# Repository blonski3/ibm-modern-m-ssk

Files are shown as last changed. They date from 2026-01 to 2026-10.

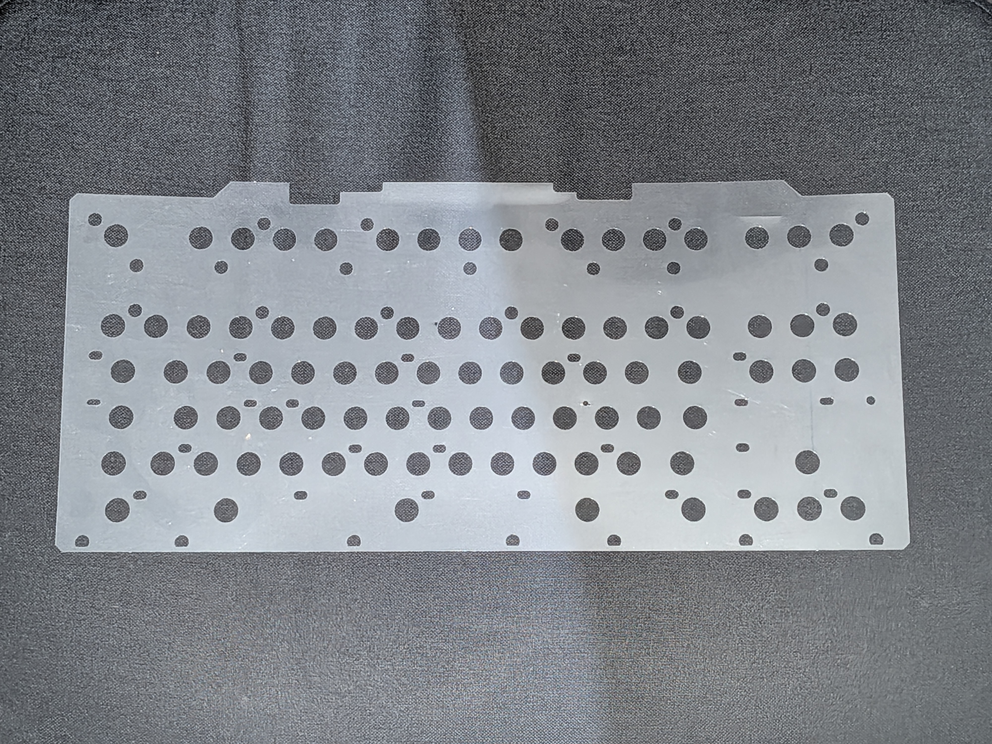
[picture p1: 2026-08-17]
docs/measurements/PXL_20260717_220600276.jpg

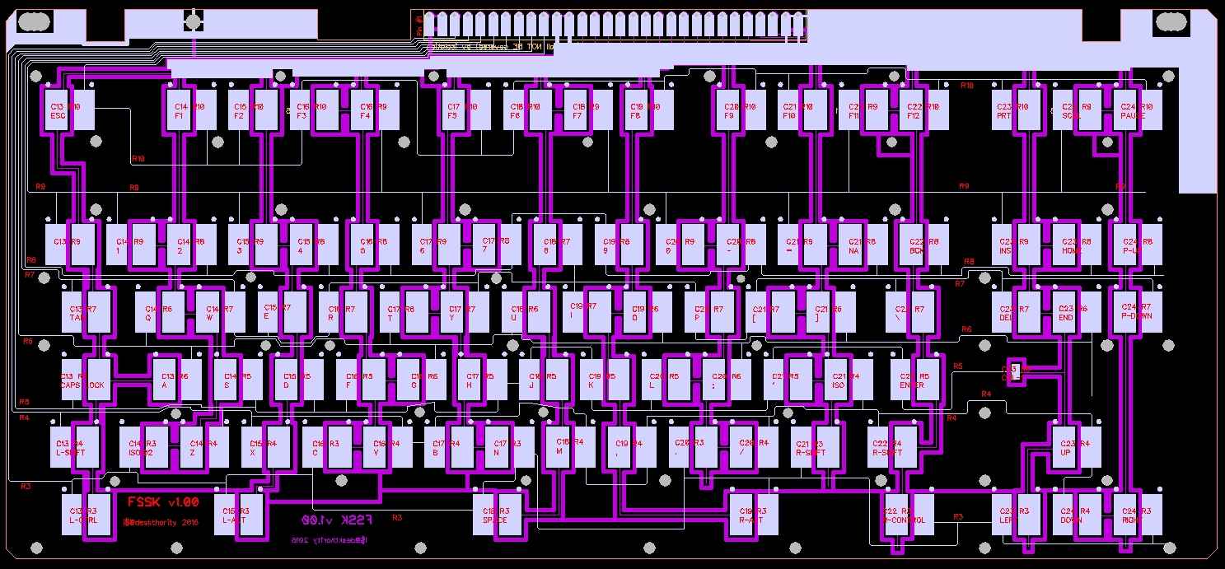
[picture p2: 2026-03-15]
docs/FSSK v1.00/FSSK Diptrace Gerber v1.00/FSSK V1.00 - All layers from Gerber.jpg

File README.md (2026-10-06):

# sources:

[Bolt Mod, A Comprehensive Tutorial: IBM Model M SSK 1991](https://imgur.com/gallery/bolt-mod-comprehensive-tutorial-ibm-model-m-ssk-1991-arUYken)

[FSSK v1.00 - Installation & Users Manual](https://deskthority.net/viewtopic.php?t=13551)

[Request for Permission to Integrate Zephyr PF1550 PMIC Drivers into ZMK #2958](https://github.com/zmkfirmware/zmk/issues/2958)

[nRF52840 Product Specification v1.5](https://docs.nordicsemi.com/viewer/book-attachment/de~7rocmcN70bRHnA4~zJA/H1GC97m6GZQEaMxKCN6OOg-de~7rocmcN70bRHnA4~zJA)

[nPM1300 Product Specification v1.3](https://docs.nordicsemi.com/viewer/book-attachment/ZO1FVHHS04YNNMSlbsZ0Kg/KbFbu1gXgIMOyTgBK7q46A-ZO1FVHHS04YNNMSlbsZ0Kg)

[Keyboard Layout Editor NG - IBM Model M](https://editor.keyboard-tools.xyz/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)

[WR-PHD Pin Header drawing](https://www.we-online.com/components/products/datasheet/61300811021.pdf)

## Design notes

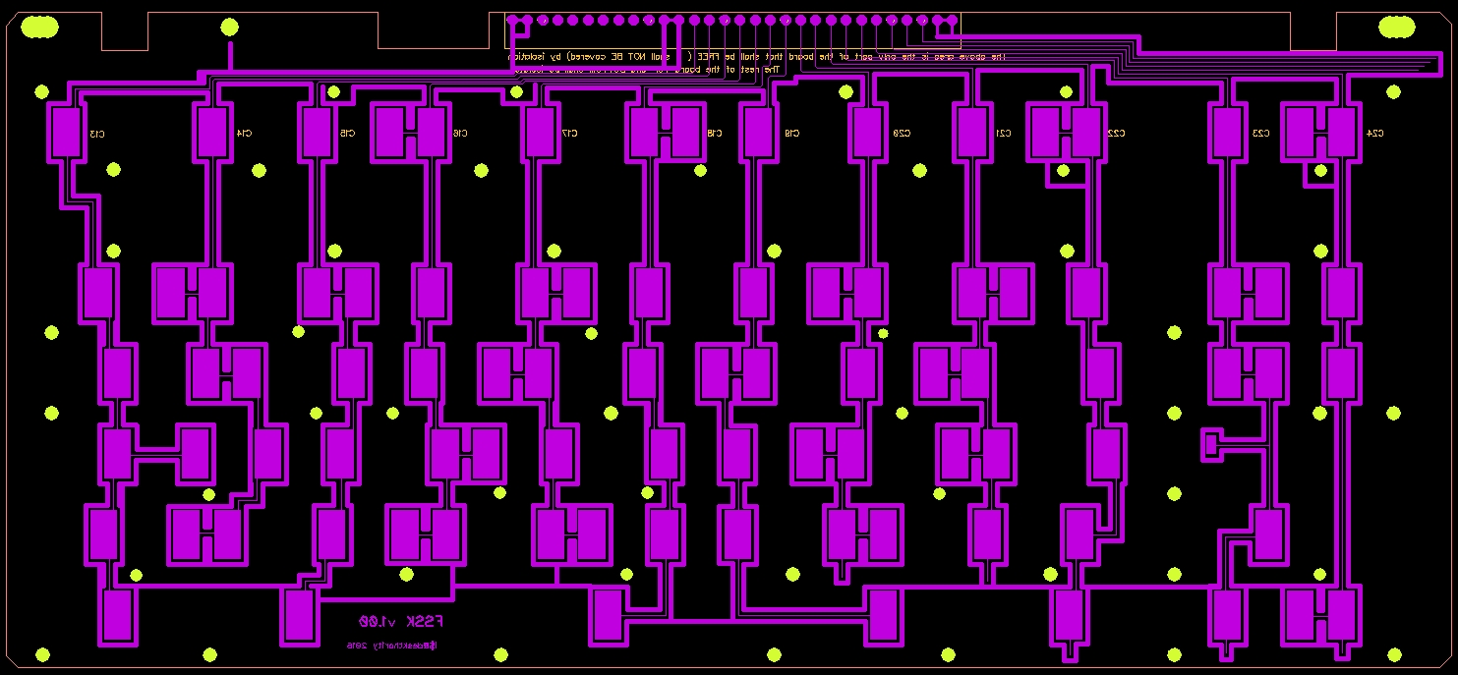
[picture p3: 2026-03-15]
docs/FSSK v1.00/FSSK Diptrace Gerber v1.00/FSSK V1.00 - Bottom layer from Gerber.jpg

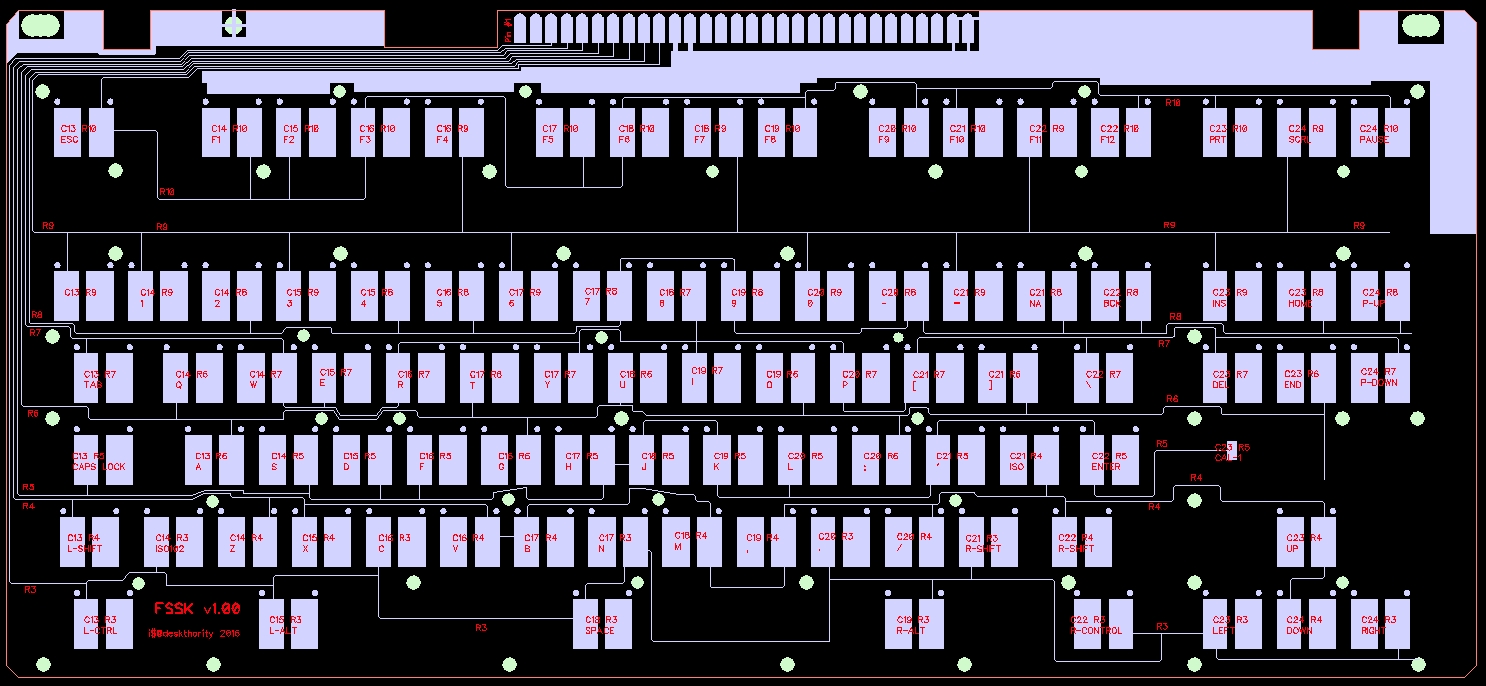
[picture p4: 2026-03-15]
docs/FSSK v1.00/FSSK Diptrace Gerber v1.00/FSSK V1.00 - Top layer from Gerber.jpg

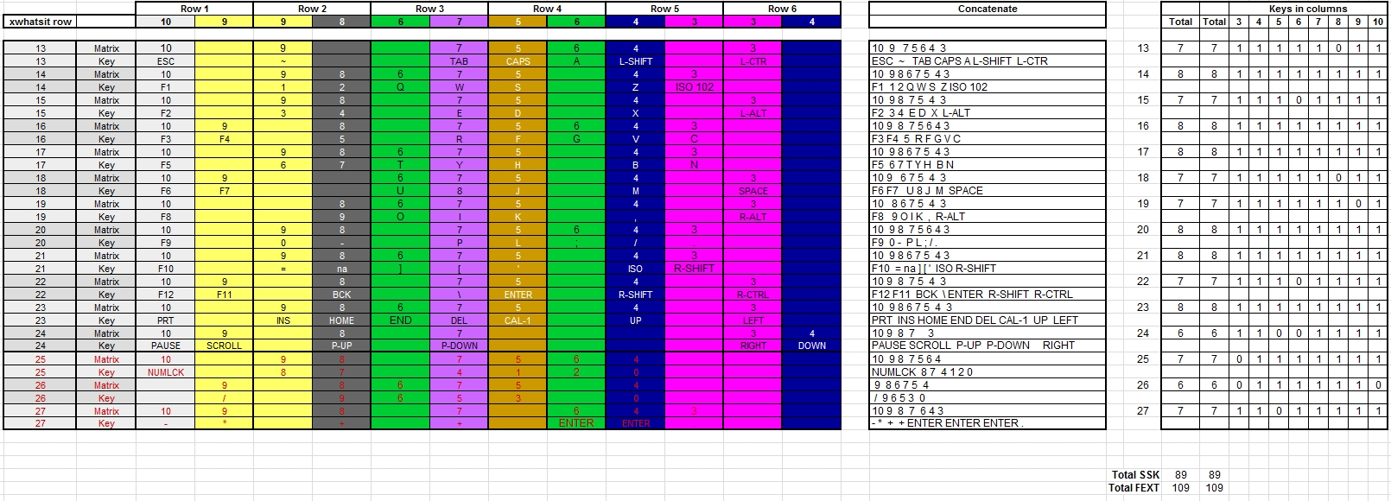
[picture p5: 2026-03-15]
docs/FSSK v1.00/FSSK v1.00 - Matrix table.jpg

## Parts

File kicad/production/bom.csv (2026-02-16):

Designator | Footprint | Quantity | Value | LCSC Part #
C1, C17, C18, C2 | 0402 | 4 | 12p | C526985
C10, C13, C22 | 0402 | 3 | NC | ~
C11 | 0402 | 1 | 100p | C106200
C12, C5, C7, C8 | 0402 | 4 | 100n | C60474
C14, C15, C27, C32, C33 | 0603 | 5 | 1u | C559769
C16 | 0402 | 1 | 47n | C327054
C20, C21, C6 | 0603 | 3 | 4.7u | C277476
C28 | 0603 | 1 | 2.2u | C309478
C29, C30, C31 | 0603 | 3 | 10u | C596327
C3 | 0402 | 1 | 0.8p | C326068
C4 | 0402 | 1 | 0.5p | C327230
C9 | 0402 | 1 | 820p | C726612
D2 | LED-SMD_4P-L1.6-W1.5-TR-1 | 1 | LED_RGB | C3029071
E1 | SON-6_L1.4-W1.0-P0.50-TL_USBULC6-2M6 | 1 | TPD2E001DRYR-TP | C2923399
J1 | FPC-SMD_24P-P0.50_TF38-24S-0.5SV-830 | 1 | TF38-24S-0.5SV(830) | C3020653
J2 | CONN-SMD_2P-P1.00_SM02B-SRSS-TB-LF-SN | 1 | S2B-PH-SM4-TB(LF)(SN) | C160402
J5 | CONN-TH_726386-2 | 1 | 726386-2 | C305817
L1 | 0402 | 1 | 4.7n | C304335
L2 | 0603 | 1 | 10u | C86083
L3 | 0402 | 1 | 15n | C381880
L4 | 1008 | 1 | 2.2u | C5349606
Q1 | SOT-23-3_L2.9-W1.3-P1.90-LS2.4-BR | 1 | DMP2123LQ | C3647032
R1 | 0402 | 1 | 10k | C25744
R10 | 0402 | 1 | 470k | C25792
R8, R9 | 0402 | 2 | 5.1k | C25905
SW90 | SW-SMD_L3.9-W3.0-P4.45 | 1 | SW_Push | C720477
U1 | AQFN50P700X700X85_HS-74N | 1 | NRF52840 | C190794
U2 | Nordic_QFN50P500X500X90-33N | 1 | nPM1300-QEAA | C7466043
USBC1 | USB-C_SMD-TYPE-C-31-M-12_1 | 1 | TYPE-C-31-M-12 | C165948
Y1 | Crystal_SMD_2016-4Pin_2.0x1.6mm | 1 | 32MHz | C255896
Y2 | Crystal_SMD_3215-2Pin_3.2x1.5mm | 1 | 32.768 kHz | C99010

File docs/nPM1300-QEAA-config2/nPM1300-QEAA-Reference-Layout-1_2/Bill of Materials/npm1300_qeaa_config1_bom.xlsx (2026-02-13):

Bill of Materials
Device: | nPM1300-QEAA
Configuration No.: | 1
Reference Layout Title: | Full – both BUCKs and LDOs, VINLDO from external sources
Revision: | 1.2
Creation Date: | 2025-06-05
Designator | Value | Description | Footprint Doc | Manufacturer | Manufacturer Part Number | #Column Name Error:' Fitted | Quantity
C1, C5 | 1.0µF | Capacitor, Ceramic, 1.0µF 10V X5R 0603,±10% | 0603 | N.A. | N.A. |  | 2
C2, C3, C4, C7, C8, C9, C10, C11, C12 | 10µF | Capacitor, X5R, ±20% | 0603 | N.A. | N.A. |  | 9
C6 | 2.2µF | Capacitor, Ceramic, X7R, ±10%, 16V | 0603 | Taiyo Yuden | EMK107BB7225KA-T |  | 1
C13 | 100nF | Capacitor, X5R, ±10%, 100nF, 16V | 0201 | N.A. | N.A. |  | 1
L1, L2 | 2.2µH | Inductor, Irms=2.5A, Isat=2.9A, ±20%, DCR=73mΩ | 0806 | Samsung Electro-Mechanics America | CIGT201610EH2R2MNE |  | 2
R1, R2 | 10k | Resistor, ±1%, 0.05W | 0201 | N.A. | N.A. |  | 2
R3 | 47k | Resistor, ±1%, 0.05W | 0201 | N.A. | N.A. |  | 1
R4 | 150k | Resistor, ±1%, 0.05W | 0201 | N.A. | N.A. |  | 1
U1 | nPM1300-QEAA | Li-Ion/Li-Polymer USB-C battery charger with high efficiency buck regulators, LDOs or load switches, LED drivers, TWI and VBUSOUT | QFN-32 | Nordic Semiconductor | nPM1300-QEAA |  | 1
 |  |  |  |  |  |  | 20

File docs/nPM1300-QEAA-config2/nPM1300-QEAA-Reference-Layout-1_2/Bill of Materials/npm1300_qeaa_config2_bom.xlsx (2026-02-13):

Bill of Materials
Device: | nPM1300-QEAA
Configuration No.: | 2
Reference Layout Title: | Simple – one BUCK, LOADSW and LED
Revision: | 1.2
Creation Date: | 2025-06-05
Designator | Value | Description | Footprint Doc | Manufacturer | Manufacturer Part Number | #Column Name Error:' Fitted | Quantity
C1, C5, C14 | 1.0µF | Capacitor, Ceramic, 1.0µF 10V X5R 0603,±10% | 0603 | N.A. | N.A. |  | 3
C2, C4, C7 | 10µF | Capacitor, Ceramic, X5R, ±20%, 10V | 0603 | N.A. | N.A. |  | 3
C6 | 2.2µF | Capacitor, Ceramic, X5R, ±10%, 25V | 0603 | Murata | GRM188R61E225KA12D |  | 1
C13 | 100nF | Capacitor, Ceramic, X5R, ±10%, 25V | 0201 | Murata | GRM033R61E104KE14J |  | 1
L1 | 2.2µH | Inductor, Irms=2.5A, Isat=2.9A, ±20%, DCR=73mΩ | 0806 | Samsung Electro-Mechanics America | CIGT201610EH2R2MNE |  | 1
R1, R2 | 10k | Resistor, ±1%, 0.05W | 0201 | N.A. | N.A. |  | 2
R3 | 47k | Resistor, ±1%, 0.05W | 0201 | N.A. | N.A. |  | 1
U1 | nPM1300-QEAA | Li-Ion/Li-Polymer USB-C battery charger with high efficiency buck regulators, LDOs or load switches, LED drivers, TWI and VBUSOUT | QFN-32 | Nordic Semiconductor | nPM1300-QEAA |  | 1
 |  |  |  |  |  |  | 13

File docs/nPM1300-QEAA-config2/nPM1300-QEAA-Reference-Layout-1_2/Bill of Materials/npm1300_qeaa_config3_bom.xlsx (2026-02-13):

Bill of Materials
Device: | nPM1300-QEAA
Configuration No.: | 3
Reference Layout Title: | Minimal – only battery charging and VSYS output
Revision: | 1.2
Creation Date: | 2025-06-05
Designator | Value | Description | Footprint Doc | Manufacturer | Manufacturer Part Number | #Column Name Error:' Fitted | Quantity
C1, C5 | 1.0µF | Capacitor, Ceramic, 1.0µF 10V X5R 0603,±10% | 0603 | N.A. | N.A. |  | 2
C4 | 10µF | Capacitor, X5R, ±20% | 0603 | N.A. | N.A. |  | 1
C6 | 2.2µF | Capacitor, Ceramic, X7R, ±10%, 16V | 0603 | Taiyo Yuden | EMK107BB7225KA-T |  | 1
C13 | 100nF | Capacitor, X5R, ±10%, 100nF, 16V | 0201 | N.A. | N.A. |  | 1
R1, R2 | 10k | Resistor, ±1%, 0.05W | 0201 | N.A. | N.A. |  | 2
U1 | nPM1300-QEAA | Li-Ion/Li-Polymer USB-C battery charger with high efficiency buck regulators, LDOs or load switches, LED drivers, TWI and VBUSOUT | QFN-32 | Nordic Semiconductor | nPM1300-QEAA |  | 1
 |  |  |  |  |  |  | 8

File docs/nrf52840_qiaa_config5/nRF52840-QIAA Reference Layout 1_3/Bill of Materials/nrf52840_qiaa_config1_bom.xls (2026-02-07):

Bill of material
Device: | nRF52840-QIAA
Title: | Reference Layout Config. 1: VBUS supply, LDO only, USB
Version: | 1.3
Designator | Value | Description | Assembly | Footprint Doc
C1, C2, C17, C18 | 12pF | Capacitor, NP0, ±2% |  | 0402
C3 | 0.8pF | Capacitor, NP0, ±10% |  | 0402
C4 | 0.5pF | Capacitor, NP0, ±10% |  | 0402
C5, C7, C8, C12 | 100nF | Capacitor, X7R, ±10% |  | 0402
C6, C20 | 4.7µF | Capacitor, X7R, ±10% |  | 0603
C9 | 820pF | Capacitor, NP0, ±5% | Not required for Fxx and later | 0402
C10, C13, C22 | N.C. | Not mounted | Not mounted | 0402
C11 | 100pF | Capacitor, NP0, ±5% |  | 0402
C14, C15 | 1.0µF | Capacitor, X7R, ±10% |  | 0603
C19 | 4.7µF | Capacitor, X7S, ±10% |  | 0603
L1 | 4.7nH | High frequency chip inductor ±5% |  | 0402
R1 | 2R2 | Resistor, ±1%, 0.063W |  | 0402
U1 | nRF52840-QIAA | Multi-protocol Bluetooth Low Energy, IEEE 802.15.4, ANT and 2.4GHz proprietary system-on-chip |  | AQFN-73
X1 | 32MHz | XTAL SMD 2016, 32MHz, Cl=8pF, Total Tol: ±40ppm |  | XTAL_2016
X2 | 32.768kHz | XTAL SMD 3215, 32.768kHz, Cl=9pF, Total Tol: ±50ppm |  | XTAL_3215

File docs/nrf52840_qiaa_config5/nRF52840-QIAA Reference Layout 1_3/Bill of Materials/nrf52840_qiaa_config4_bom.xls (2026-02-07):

Bill of material
Device: | nRF52840-QIAA
Title: | Reference Layout Config. 4: VDDH supply, DCDC, USB
Version: | 1.3
Designator | Value | Description | Assembly | Footprint Doc
C1, C2, C17, C18 | 12pF | Capacitor, NP0, ±2% |  | 0402
C3 | 0.8pF | Capacitor, NP0, ±10% |  | 0402
C4 | 0.5pF | Capacitor, NP0, ±10% |  | 0402
C5, C7, C8, C12 | 100nF | Capacitor, X7R, ±10% |  | 0402
C6, C20 | 4.7µF | Capacitor, X7R, ±10% |  | 0603
C9 | 820pF | Capacitor, NP0, ±5% | Not required for Fxx and later | 0402
C10, C13, C22 | N.C. | Not mounted | Not mounted | 0402
C11 | 100pF | Capacitor, NP0, ±5% |  | 0402
C14, C15 | 1.0µF | Capacitor, X7R, ±10% |  | 0603
C16 | 47nF | Capacitor, X7R, ±10% |  | 0402
C19, C21 | 4.7µF | Capacitor, X7S, ±10% |  | 0603
L1 | 4.7nH | High frequency chip inductor ±5% |  | 0402
L2 | 10µH | Chip inductor, IDC,min = 50 mA, ±20% |  | 0603
L3 | 15nH | High frequency chip inductor ±10% |  | 0402
L4 | 10µH | Chip inductor, IDC,min = 80 mA, ±20% |  | 0603
U1 | nRF52840-QIAA | Multi-protocol Bluetooth Low Energy, IEEE 802.15.4, ANT and 2.4GHz proprietary system-on-chip |  | AQFN-73
X1 | 32MHz | XTAL SMD 2016, 32MHz, Cl=8pF, Total Tol: ±40ppm |  | XTAL_2016
X2 | 32.768kHz | XTAL SMD 3215, 32.768kHz, Cl=9pF, Total Tol: ±50ppm |  | XTAL_3215

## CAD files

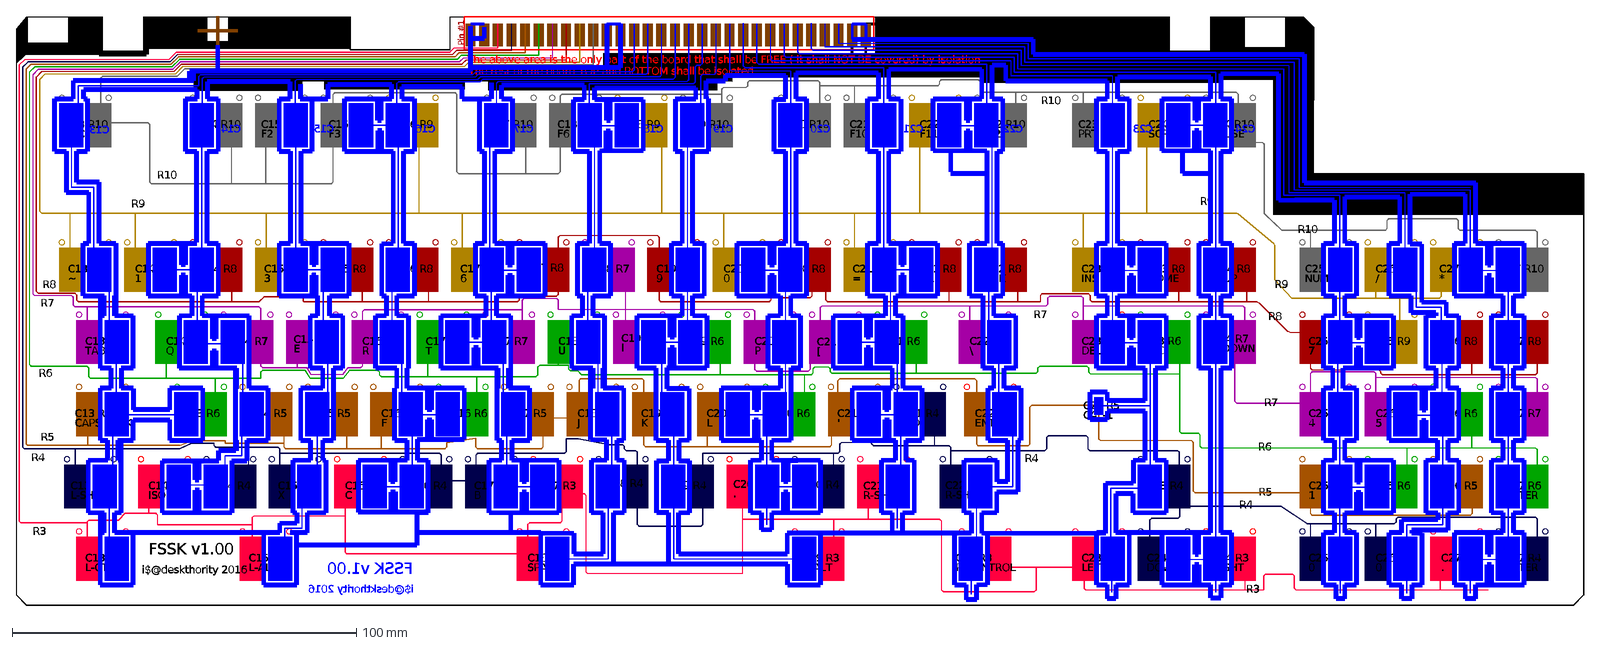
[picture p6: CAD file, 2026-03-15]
docs/FSSK v1.00/FSSK 1.00.dxf
Pin #1
C26 R9
/
C25 R10
NUMLCK
C27 R9
*
C27 R10
-
C25 R8
7
C25 R9
8
C26 R8
9
C27 R8
+
C25 R7
4
C26 R7
5
C26 R6
6
C27 R7
C25 R5
1
C25 R6
2
C26 R5
3
C27 R6
ENTER
C25 R4
0
C26 R4
C27 R3
.
C27 R4
C24 R3
RIGHT
C24 R4
DOWN
C23 R3
LEFT
C23 R4
UP
C23 R7
DEL
C23 R6
END
C24 R7
P-DOWN
C23 R9
INS
C23 R8
HOME
C24 R8
P-UP
C23 R10
PRT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

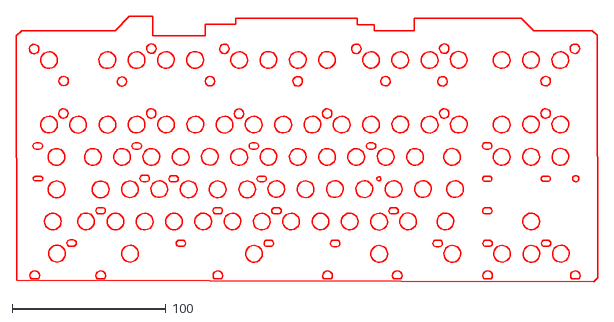
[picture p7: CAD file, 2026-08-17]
docs/measurements/drawing.dxf
377.7 x 172.3

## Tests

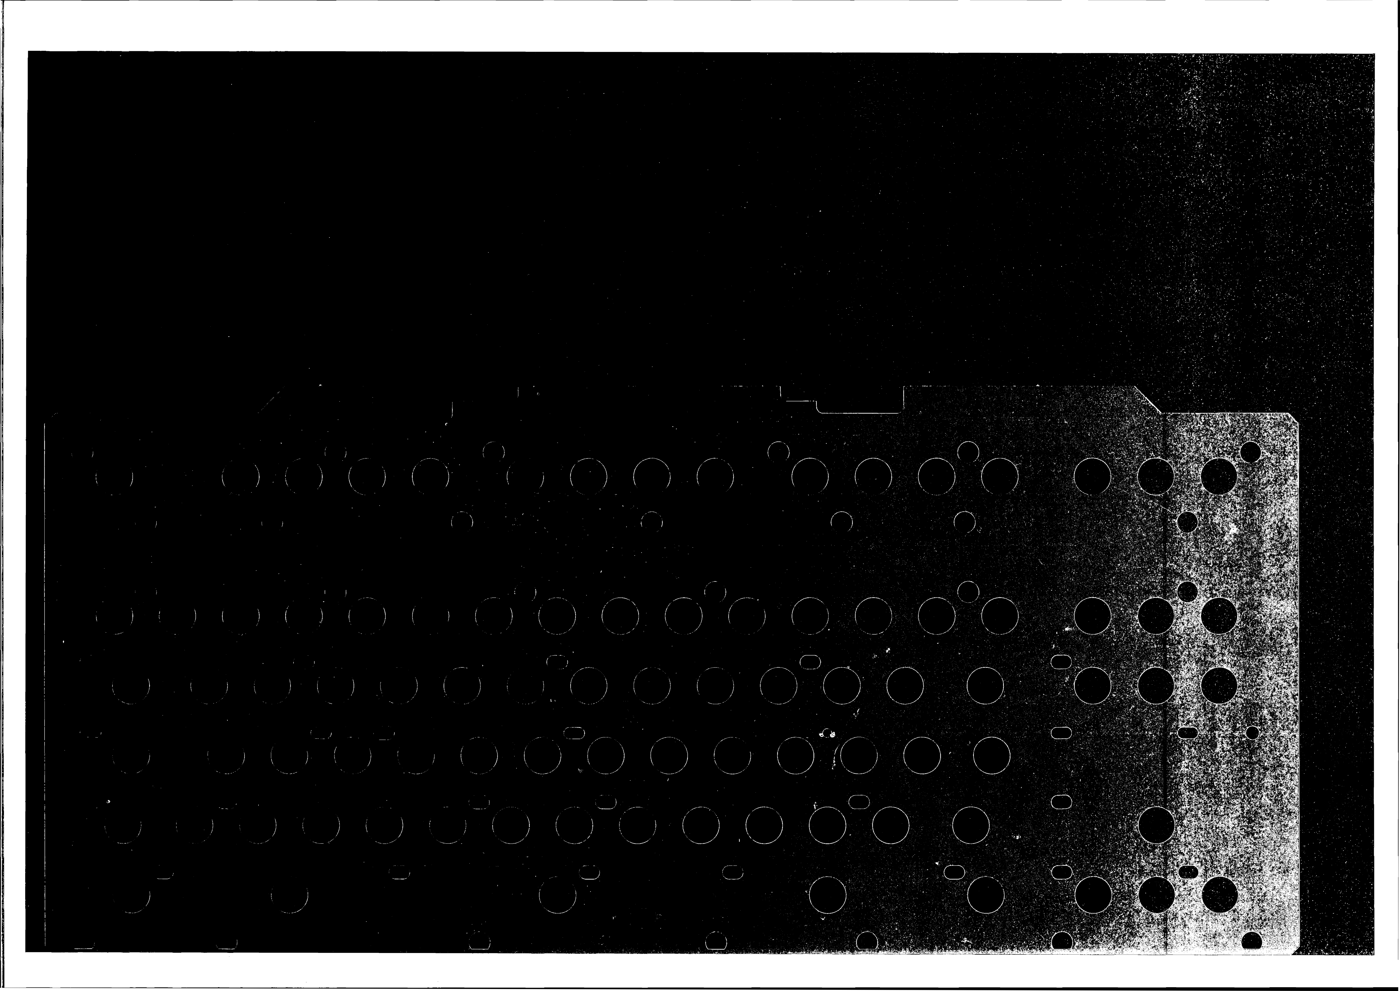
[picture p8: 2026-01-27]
docs/measurements/seperating layer scan.png

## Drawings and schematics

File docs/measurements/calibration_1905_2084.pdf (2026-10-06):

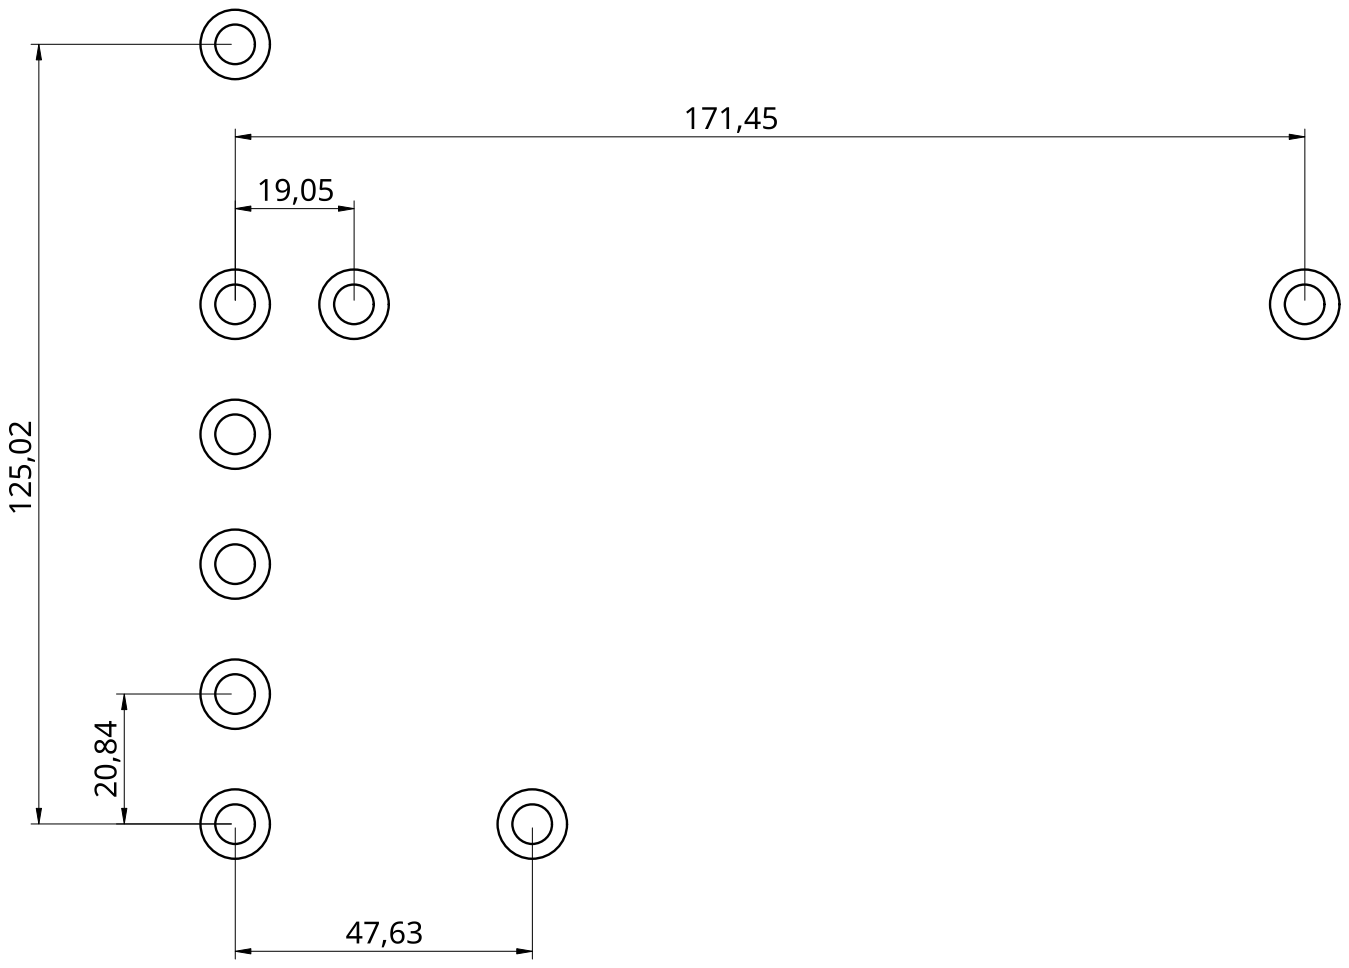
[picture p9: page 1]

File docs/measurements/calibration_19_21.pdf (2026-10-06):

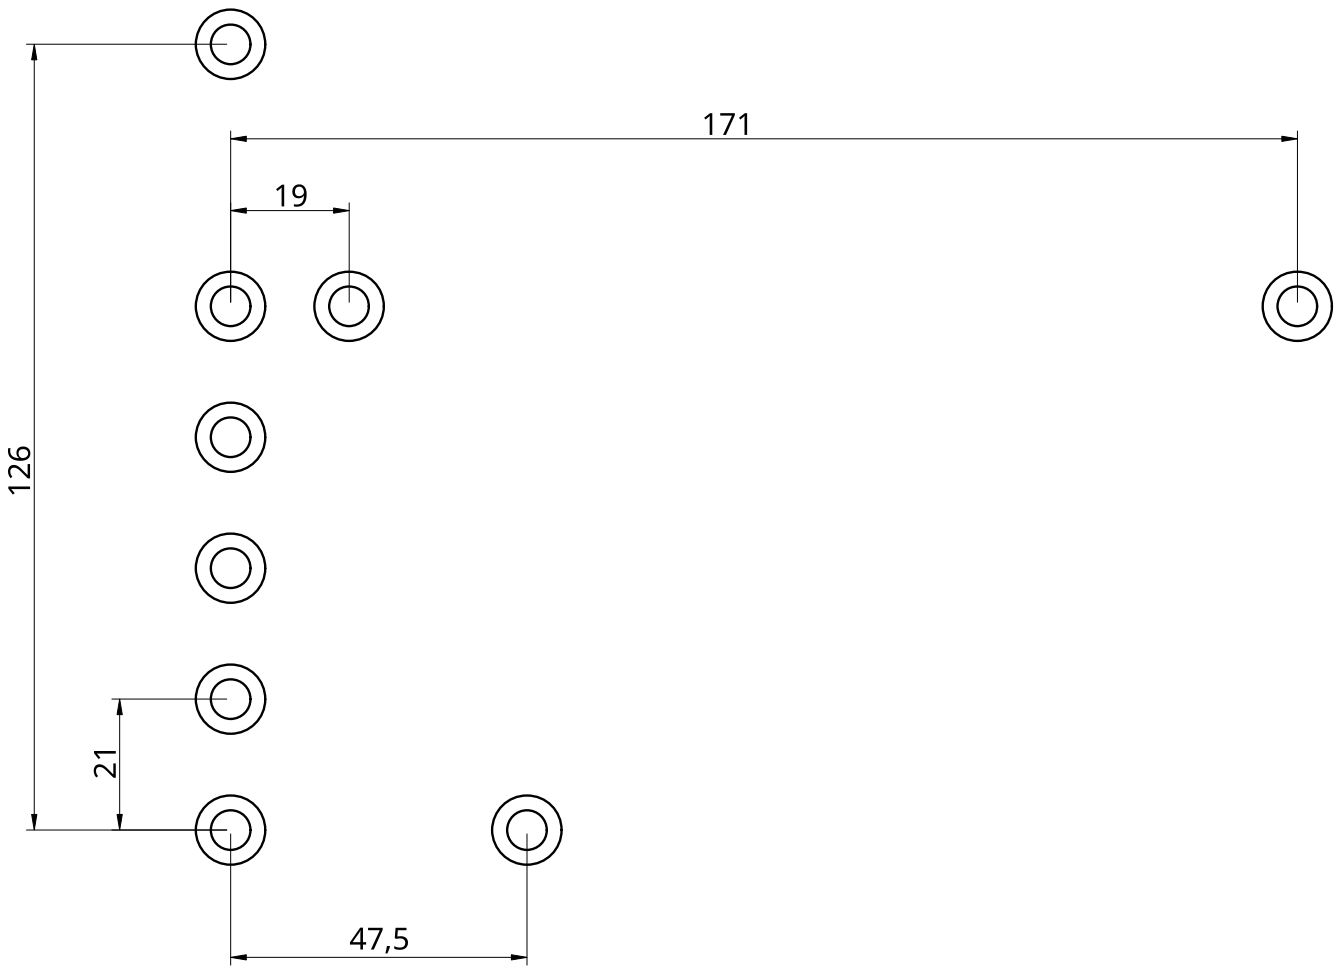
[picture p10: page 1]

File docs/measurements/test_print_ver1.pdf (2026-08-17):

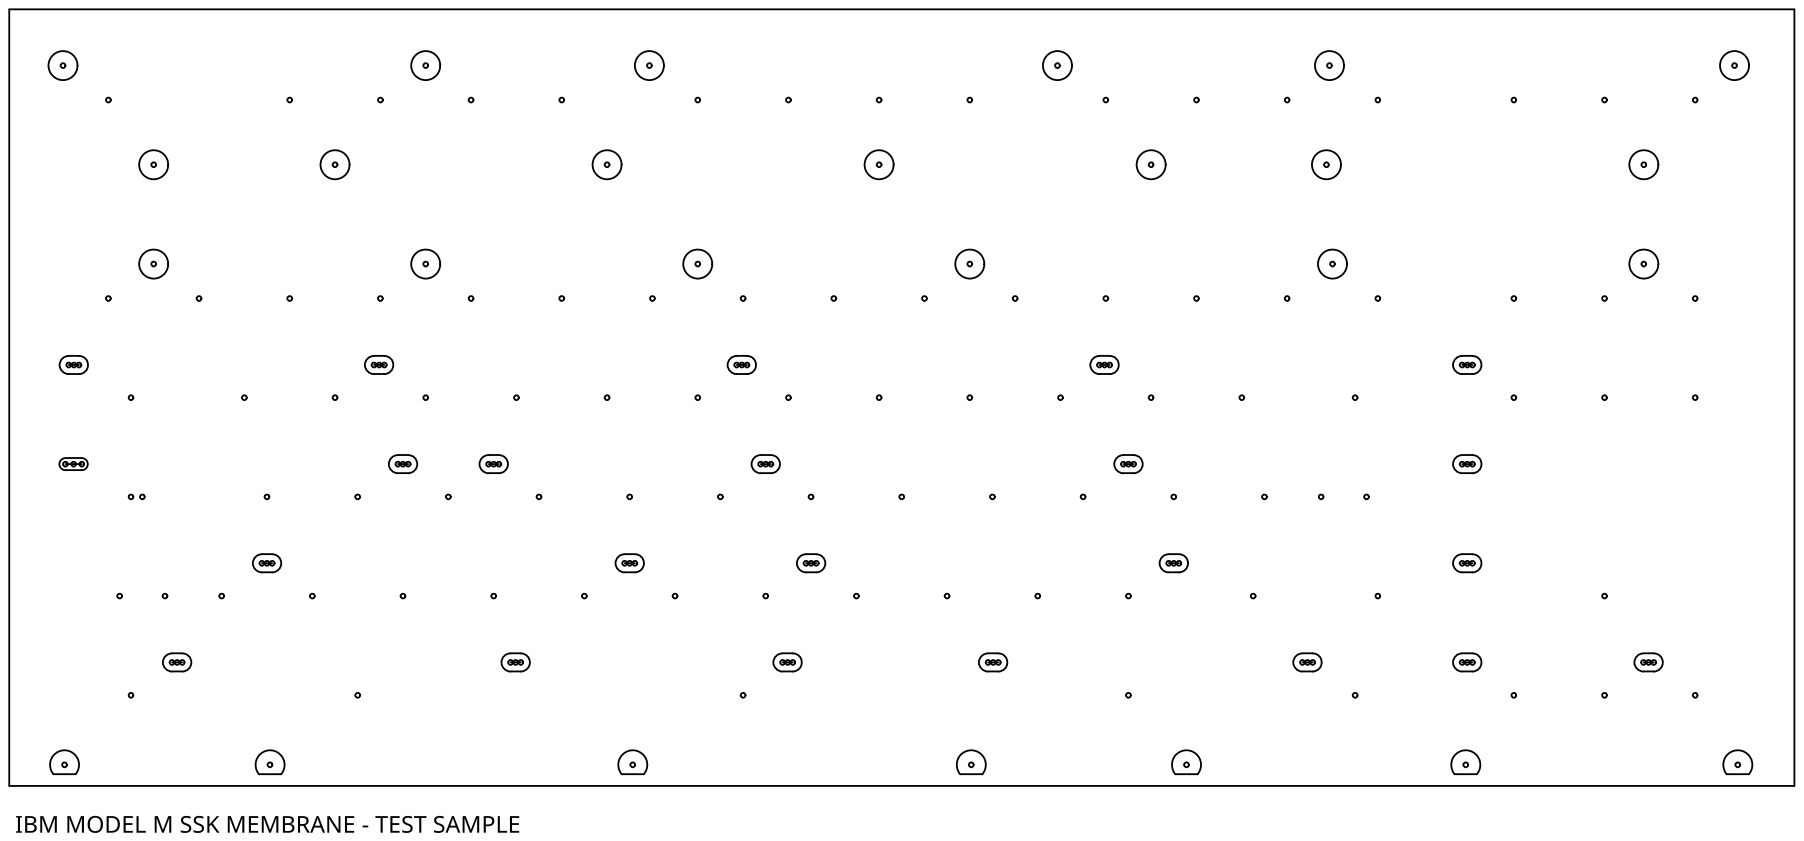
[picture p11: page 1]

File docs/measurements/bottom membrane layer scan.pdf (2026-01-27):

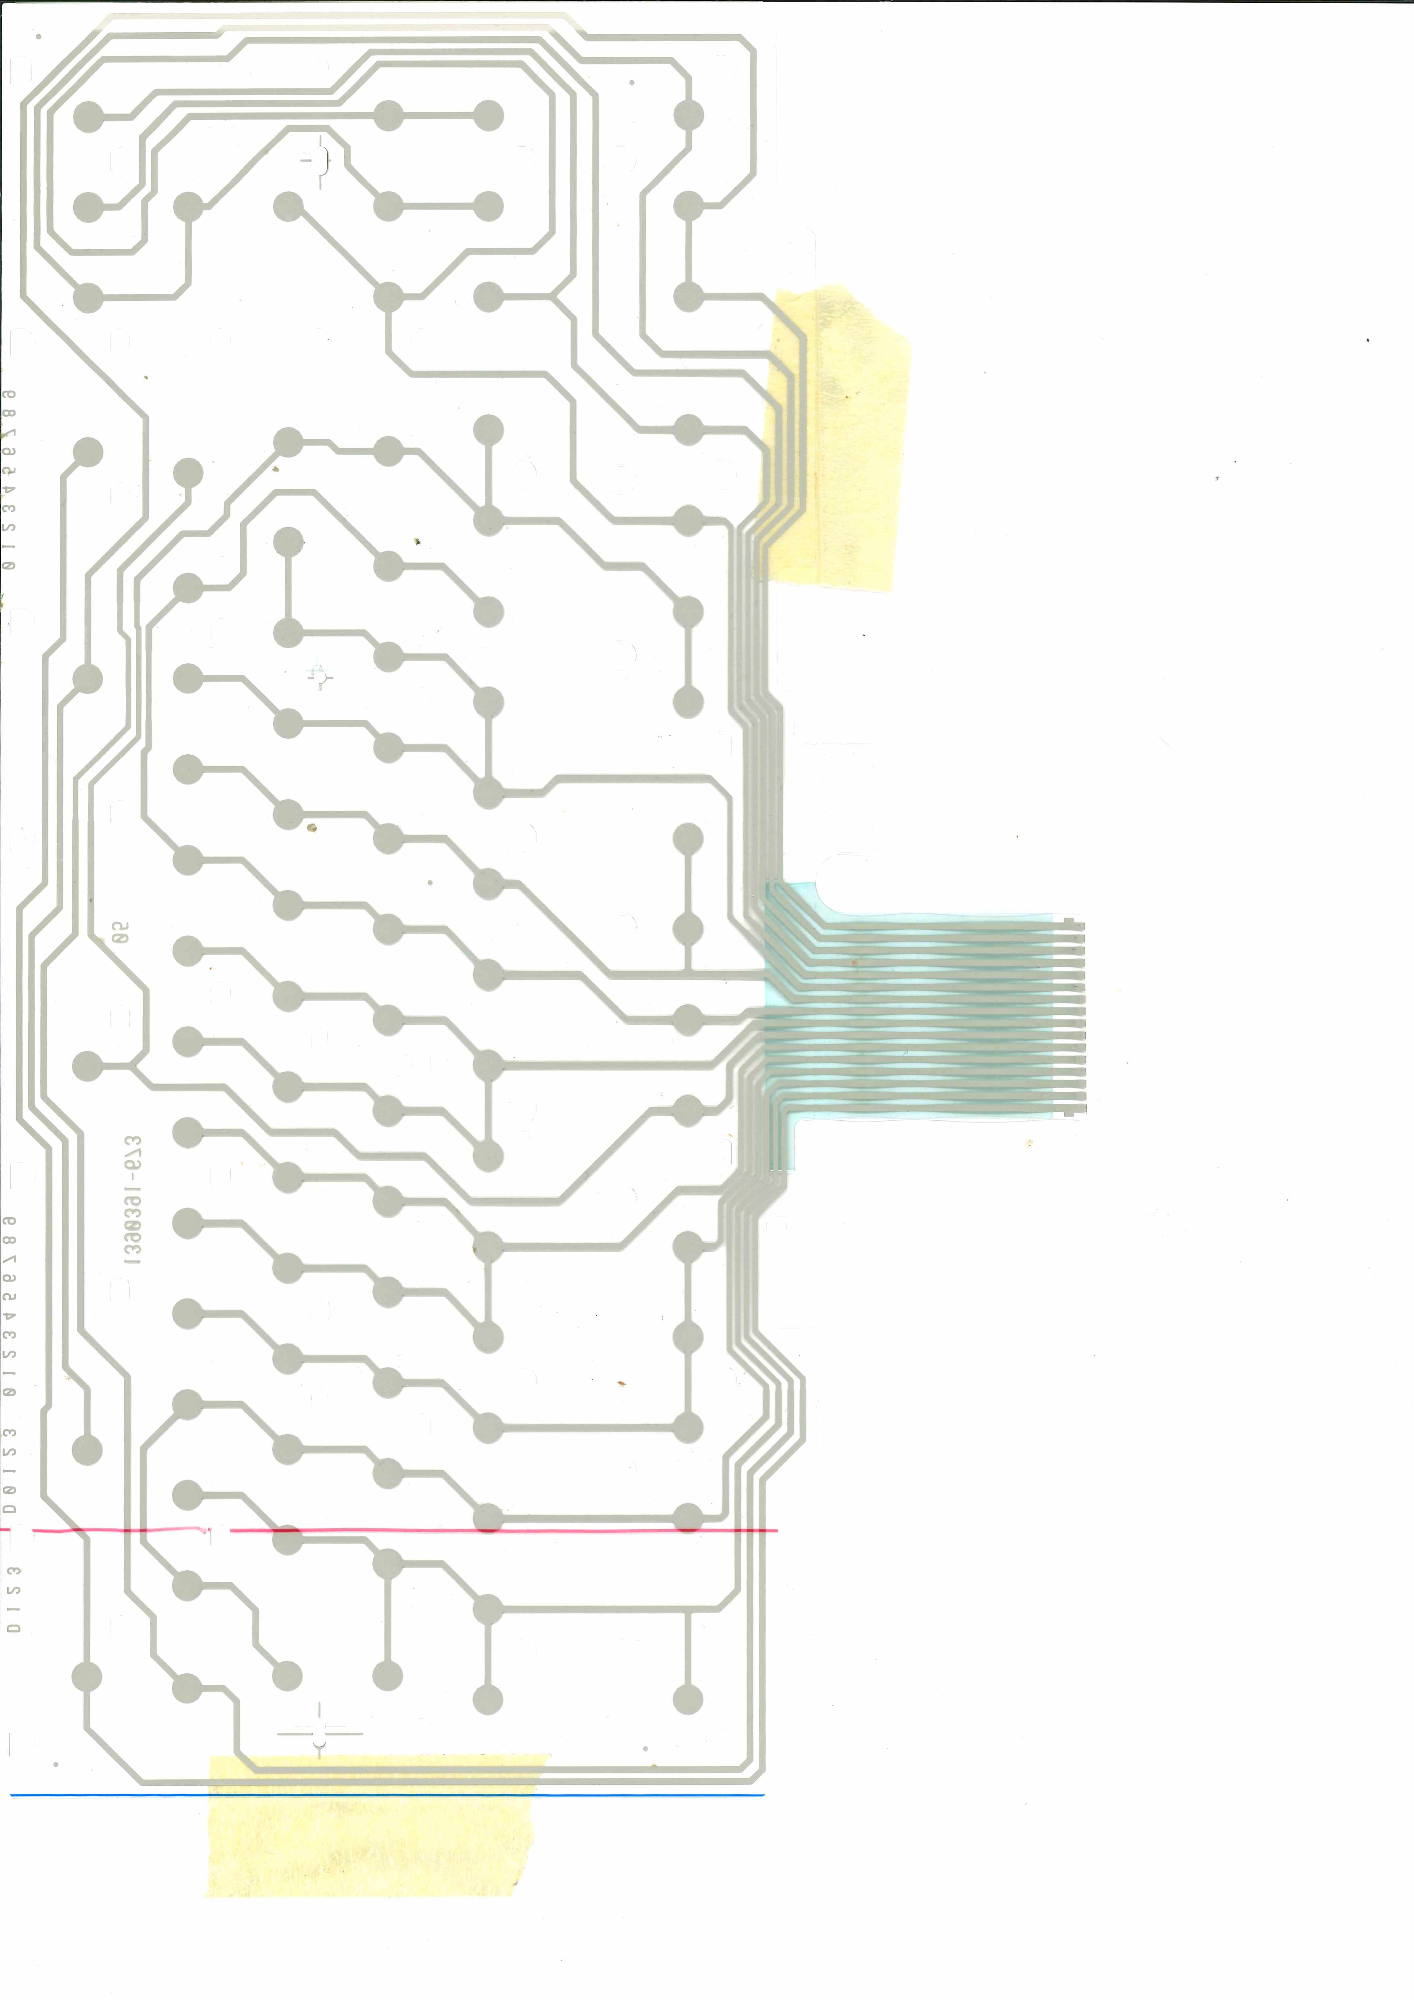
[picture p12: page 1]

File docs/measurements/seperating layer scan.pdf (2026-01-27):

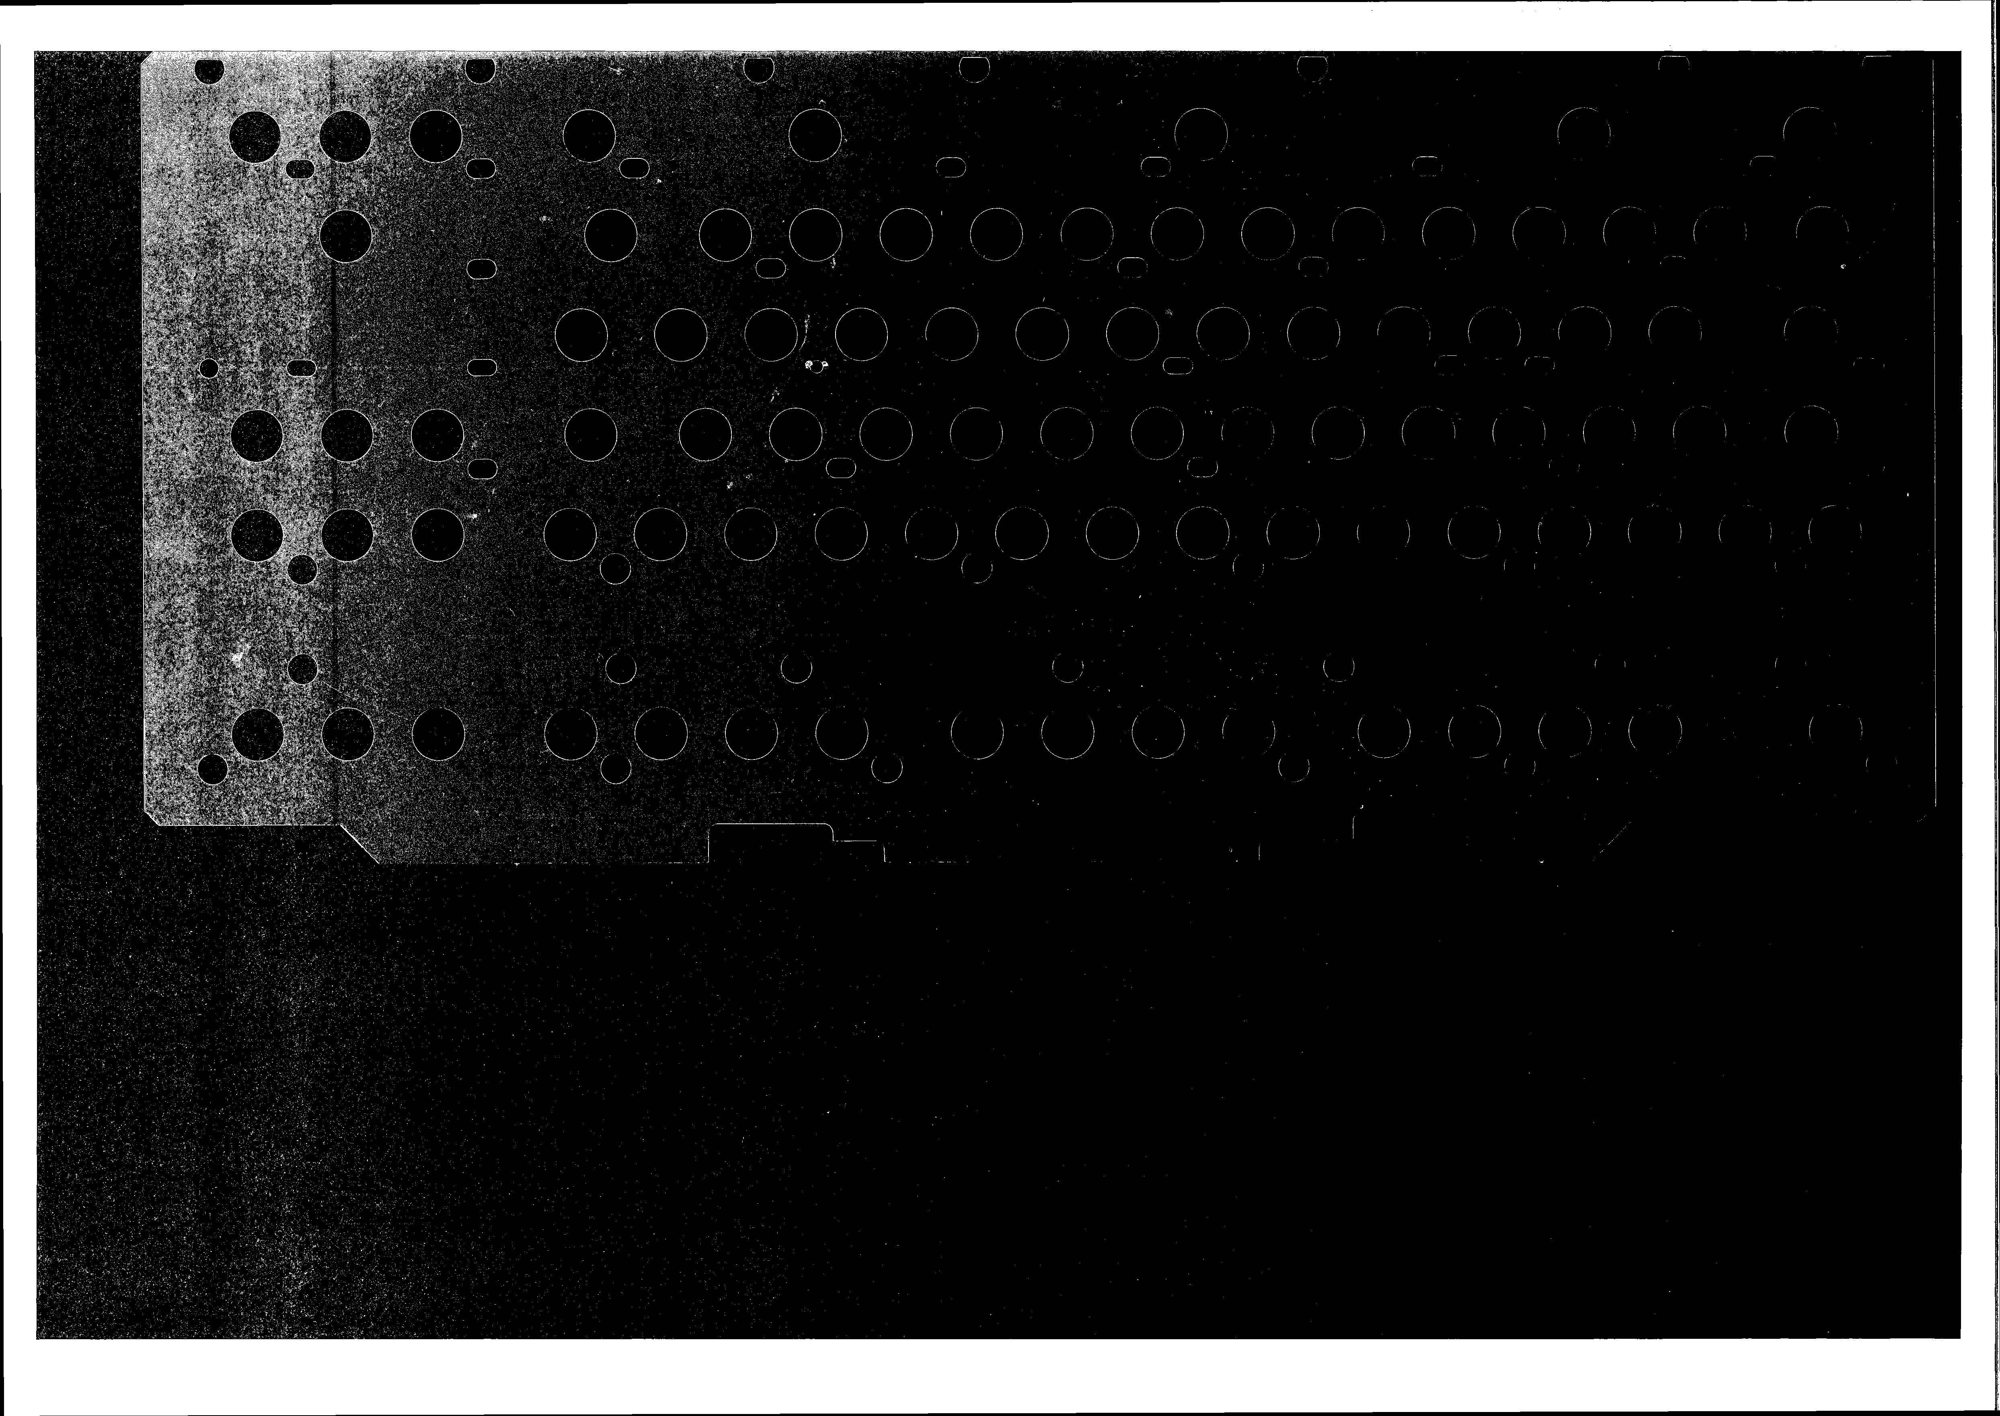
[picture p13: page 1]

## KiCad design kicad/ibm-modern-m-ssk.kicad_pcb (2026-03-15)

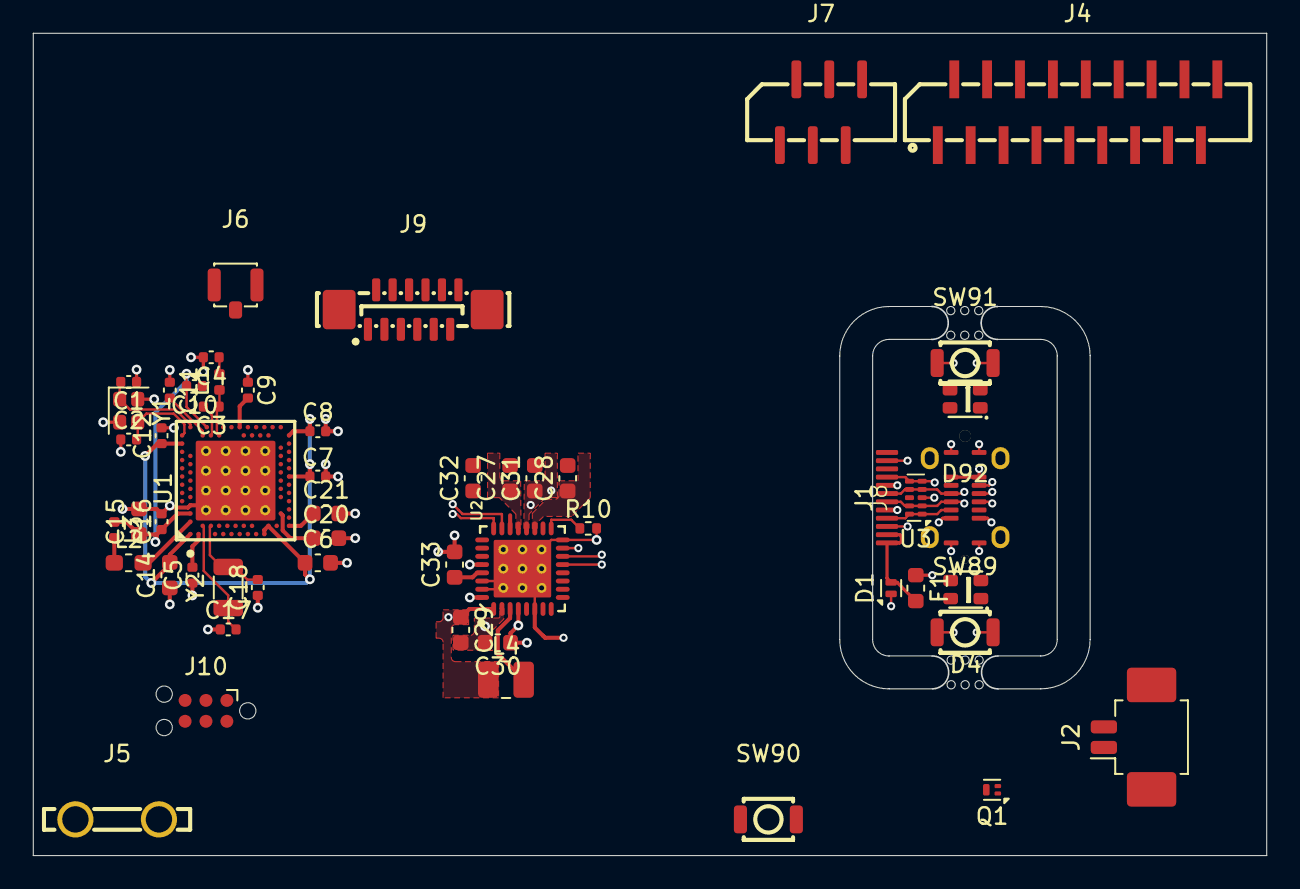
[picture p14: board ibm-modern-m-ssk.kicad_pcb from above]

Board: 4 copper layers, 75.0 x 50.0 mm, 53 parts (0 on the bottom side), 35 nets.

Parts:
C1, C2, C17, C18: 12p; C_0402_1005Metric
C3: 0.8p; C_0402_1005Metric
C4: 0.5p; C_0402_1005Metric
C5, C7, C8, C12: 100n; C_0402_1005Metric
C6, C20, C21: 4.7u; C_0603_1608Metric
C9: 820p; C_0402_1005Metric
C10: NC; C_0402_1005Metric
C11: 100p; C_0402_1005Metric
C14, C15, C27, C32, C33: 1u; C_0603_1608Metric
C16: 47n; C_0402_1005Metric
C28: 2.2u; C_0603_1608Metric
C29, C30, C31: 10u; C_0603_1608Metric
D1: PESDNC2FD5VB; Diodes_DFN1006-2
D4, D92: rgb; WS2812C-2020-V1
F1: BSMD0603L-150; Fuse_0603_1608Metric
J1: TYPE-C-31-D-06; USB-C-SMD_TYPE-C-31-D-06
J2: Molex PicoBlade; Molex_PicoBlade_53261-0271_1x02-1MP_P1.25mm_Horizontal
J4: AFB10-S18LCA-00; FPC-SMD_18P-P1.00_AFB10-S18LCA-00
J5: 726386-2; CONN-TH_726386-2
J6: Conn_Coaxial_Small; IPEX-SMD_3P-L2.6-W2.6-LS3.0_ZCF-CF0001-0002IPEX
J7: AFB10-S06LCA-00; FPC-SMD_6P-P1.00_AFB10-S6LCA-00
J8: FPC_12P_0.5mm
J9: AFC11-S12ICA-00; CONN-SMD-12P_AFC11-S12ICA-00
J10: TC2030; Tag-Connect_TC2030-IDC-NL_2x03_P1.27mm_Vertical
L1: 4.7n; L_0402_1005Metric
L2: 10u; L_0603_1608Metric_Pad1.05x0.95mm_HandSolder
L3: 15n; L_0402_1005Metric
L4: 2.2u; L_1008_2520Metric
Q1: PMZB350UPE,315; DFN1006-3
R10: 470k; R_0402_1005Metric
SW89, SW90, SW91: SW_Push; KEY-SMD_B3U-1000PM
U1: NRF52840; AQFN50P700X700X85_HS-74N
U2: nPM1300-QEAA; Nordic_QFN50P500X500X90-33N
U3: TPD4E05U06DQAR; USON-10_2.5x1.0mm_P0.5mm
Y1: 32MHz; Crystal_SMD_2016-4Pin_2.0x1.6mm
Y2: 32.768 kHz; Crystal_SMD_3215-2Pin

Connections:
/daughterboard/BT_PAIR: J8.3, J9.3, SW89.1
/daughterboard/CC1: J1.A5 (CC1), J8.4, J9.4, U2.23 (CC1), U3.1 (D1+), U3.10 (NC)
/daughterboard/CC2: J1.B5 (CC2), J8.9, J9.9, U2.24 (CC2), U3.5 (D2-), U3.6 (NC)
/daughterboard/LED_DATA: D4.3 (DIN), J8.10, J9.10
/daughterboard/SHPHLD: J8.11, J9.11, SW91.1, U2.15 (SHPHLD)
/motherboard/ANTENNA: C4.1, J6.1 (In), L1.2
/motherboard/DEC4: C10.2, C15.1, C16.1, L3.1, U1.B5 (DEC4), U1.E24 (DEC6)
/motherboard/SWCLK: J10.4, U1.AA24 (SWDCLK)
/motherboard/SWDIO: J10.2, U1.AC24 (SWDIO)
D+: J1.A6 (D+), J1.B6 (D+), J8.6, J9.6, U1.AD6 (D+), U3.2 (D1-), U3.9 (NC)
D-: J1.A7 (D-), J1.B7 (D-), J8.7, J9.7, U1.AD4 (D-), U3.4 (D2+), U3.7 (NC)
GND: C1.1, C2.1, C3.2, C4.2, C5.1, C6.2, C7.2, C8.2, C9.2, C10.1, C11.1, C12.2, C14.1, C15.2, C16.2, C17.1, C18.1, C20.2, C21.2, C27.2, C28.2, C31.2, C32.2, C33.2, D1.1 (A1), D4.2 (VSS), D92.2 (VSS), J1.A1 (GND), J1.A12 (GND), J1.B1 (GND), J1.B12 (GND), J2.2, J5.1, J6.2 (Ext), J8.5, J8.8, J9.5, J9.8, J10.3, J10.5, Q1.1 (G), R10.2, SW89.2, SW90.2, SW91.2, U1.74 (GND), U1.B7 (VSS), U1.F23 (VSS_PA), U2.6 (PVSS2), U2.16 (VSET2), U2.30 (LSIN2/VINLDO2), U2.31 (LSOUT2/VOUTLDO2), U2.33 (AVSS), U3.3 (GND), U3.8 (GND), Y1.2, Y1.4
unnamed: D4.1 (DOUT), D92.3 (DIN)
unnamed: F1.1, J1.A4 (VBUS), J1.A9 (VBUS), J1.B4 (VBUS), J1.B9 (VBUS)
unnamed: L2.1, L3.2
unnamed: J2.1, Q1.2 (S)
unnamed: C3.1, L1.1, U1.H23 (ANT)
unnamed: L2.2, U1.B3 (DCC)
unnamed: C5.2, U1.C1 (DEC1)
unnamed: C11.2, U1.D23 (DEC3)
unnamed: C9.1, U1.N24 (DEC5)
unnamed: C20.1, U1.AC5 (DECUSB)
unnamed: C17.2, U1.D2 (P0.00/XL1), Y2.2
unnamed: C18.2, U1.F2 (P0.01/XL2), Y2.1
unnamed: C1.2, U1.B24 (XC1), Y1.3
unnamed: C2.2, U1.A23 (XC2), Y1.1
unnamed: C33.1, U2.29 (LSOUT1/VOUTLDO1)
unnamed: L4.2, U2.3 (SW1)
unnamed: R10.1, U2.17 (VSET1)
PVSS1: C29.2, C30.2, U2.2 (PVSS1)
VBAT: C28.1, Q1.3 (D), U2.19 (VBAT)
VBUS: C27.1, D1.2 (A2), F1.2, J8.1, J8.2, J9.1, J9.2, U2.21 (VBUS)
VBUSOUT: C21.1, C32.1, U1.AD2 (VBUS), U2.22 (VBUSOUT)
VDD_NRF: C6.1, C7.1, C8.1, C12.1, C14.2, C29.1, J10.1, L4.1, U1.A22 (VDD), U1.AD14 (VDD), U1.AD23 (VDD), U1.B1 (VDD), U1.W1 (VDD), U1.Y2 (VDDH), U2.1 (VOUT1), U2.28 (LSIN1/VINLDO1)
VSYS: C30.1, C31.1, D4.4 (VDD), D92.4 (VDD), J8.12, J9.12, U2.4 (PVDD), U2.20 (VSYS), U2.32 (VOUT2)

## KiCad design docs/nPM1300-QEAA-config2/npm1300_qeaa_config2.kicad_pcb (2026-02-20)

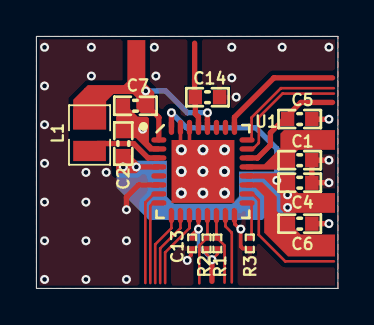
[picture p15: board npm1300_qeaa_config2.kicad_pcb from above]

Board: 4 copper layers, 16.8 x 14.0 mm, 14 parts (0 on the bottom side), 13 nets.

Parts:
C1, C5, C14: 1.0µF; CAPC1608X06L
C2, C4, C7: 10µF; CAPC1608X06L
C6: 2.2µF; CAPC1608X06L
C13: 100nF; CAPC0603X03L_C
L1: 2.2µH; INDC2016X10N
NT1: Net tie; 2 PIN STARPOINT
R1, R2: 10k; RESC0603X03L_C
R3: 47k; RESC0603X03L_C
U1: nPM1300-QEAA; Nordic_QFN50P500X500X90-33N

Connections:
GND: C1.1, C4.1, C5.1, C6.1, C13.2, C14.1, NT1.1, R3.2, U1.6, U1.16, U1.30, U1.31, U1.33
LSOUT1: C14.2, U1.29
PVSS1: C2.1, C7.1, NT1.2, U1.2
SCL: R1.1, U1.14
SDA: R2.1, U1.13
SW1: L1.2, U1.3
VBAT: C6.2, U1.19
VBUSIN: C1.2, U1.21
VBUSOUT: C5.2, U1.22
VDDIO: C13.1, R1.2, R2.2, U1.12
VOUT1: C7.2, L1.1, U1.1, U1.28
VSET1: R3.1, U1.17
VSYS: C2.2, C4.2, U1.4, U1.20, U1.32

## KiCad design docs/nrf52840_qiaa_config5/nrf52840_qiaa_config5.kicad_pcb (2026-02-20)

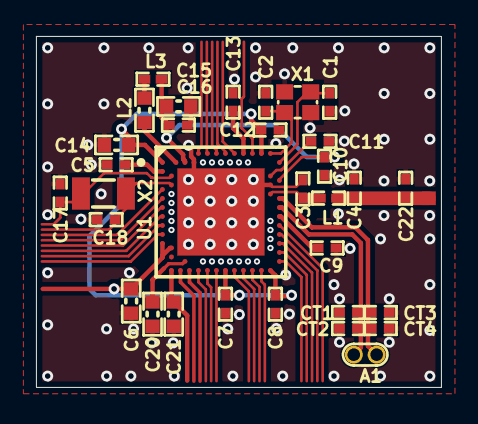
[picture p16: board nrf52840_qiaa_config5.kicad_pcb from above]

Board: 4 copper layers, 22.5 x 19.5 mm, 32 parts (0 on the bottom side), 19 nets.

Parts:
A1: NFC Antenna; TP_2x1mm_TH
C1, C2, C17, C18: 12pF; CAPC1005X04L
C3: 0.8pF; CAPC1005X04L
C4: 0.5pF; CAPC1005X04L
C5, C7, C8, C12: 100nF; CAPC1005X04L
C6, C20, C21: 4.7µF; CAPC1608X06L
C9: 820pF; CAPC1005X04L
C10, C13, C22: N.C.; CAPC1005X04L
C11: 100pF; CAPC1005X04L
C14, C15: 1.0µF; CAPC1608X06L
C16: 47nF; CAPC1005X04L
CT1, CT2, CT3, CT4: Antenna dependent; CAPC1005X04L
L1: 4.7nH; INDC1005X04L
L2: 10µH; INDC1608X06L
L3: 15nH; INDC1005X04L
U1: nRF52840-QIAA; AQFN50P700X700X85_HS-74N
X1: 32MHz; BT-XTAL_2016
X2: 32.768kHz; XTAL_3215

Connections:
DEC1: C5.1, U1.C1
DEC3: C11.1, U1.D23
DEC4_6: C10.2, C15.2, C16.1, L3.1, U1.B5, U1.E24
GND: C1.2, C2.2, C3.1, C4.1, C5.2, C6.2, C7.2, C8.2, C9.2, C10.1, C11.2, C12.2, C13.2, C14.2, C15.1, C16.2, C17.2, C18.2, C20.2, C21.2, C22.2, CT1.2, CT2.2, CT3.1, CT4.1, U1.74, U1.B7, U1.F23, X1.2, X1.4
NFC1: A1.2, CT1.1, CT2.1, U1.L24
NFC2: A1.1, CT3.2, CT4.2, U1.J24
NetC3_2: C3.2, L1.1, U1.H23
NetC9_1: C9.1, U1.N24
NetC13_1: C13.1, U1.A18
NetC20_1: C20.1, U1.AC5
NetL2_1: L2.1, L3.2
NetL2_2: L2.2, U1.B3
P0.00/XL1: C17.1, U1.D2, X2.1
P0.01/XL2: C18.1, U1.F2, X2.2
RF: C4.2, C22.1, L1.2
VBUS: C21.1, U1.AD2
VDD_NRF: C6.1, C7.1, C8.1, C12.1, C14.1, U1.A22, U1.AD14, U1.AD23, U1.B1, U1.W1, U1.Y2
XC1: C1.1, U1.B24, X1.1
XC2: C2.1, U1.A23, X1.3

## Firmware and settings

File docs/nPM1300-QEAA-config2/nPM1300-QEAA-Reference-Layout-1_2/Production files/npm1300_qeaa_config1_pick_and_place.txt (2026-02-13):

Altium Designer Pick and Place Locations
C:\nordic\applications\reference_layouts\npm1300_qeaa\trunk\production_files\npm1300_qeaa_config1_pick_and_place.txt

========================================================================================================================
File Design Information:

Date:       05-06-25
Time:       13:23
Revision:   37394
Variant:    No variations
Units used: mil

Designator Comment      Layer    Footprint                   Center-X(mil) Center-Y(mil) Rotation Description                                                                                                                         
U1         nPM1300-QEAA TopLayer Nordic_QFN50P500X500X90-33N 0.000         0.000         0        "Li-Ion/Li-Polymer USB-C battery charger with high efficiency buck regulators, LDOs or load switches, LED drivers, TWI and VBUSOUT" 
C13        100nF        TopLayer CAPC0603X03L_C              -23.622       -157.480      270      "Capacitor, X5R, ±10%, 100nF, 16V"                                                                                                  
C12        10µF         TopLayer CAPC1608X06L                -70.866       216.535       270      "Capacitor, X5R, ±20%"                                                                                                              
C11        10µF         TopLayer CAPC1608X06L                -23.622       216.535       270      "Capacitor, X5R, ±20%"                                                                                                              
C10        10µF         TopLayer CAPC1608X06L                23.622        216.535       270      "Capacitor, X5R, ±20%"                                                                                                              
C9         10µF         TopLayer CAPC1608X06L                70.866        216.535       270      "Capacitor, X5R, ±20%"                                                                                                              
C8         10µF         TopLayer CAPC1608X06L                -250.984      -114.173      180      "Capacitor, X5R, ±20%"                                                                                                              
R4         150k         TopLayer RESC0603X03L_C              82.677        -157.480      270      "Resistor, ±1%, 0.05W"                                                                                                              
R3         47k          TopLayer RESC0603X03L_C              106.299       -157.480      270      "Resistor, ±1%, 0.05W"                                                                                                              
R2         10k          TopLayer RESC0603X03L_C              7.874         -157.480      270      "Resistor, ±1%, 0.05W"                                                                                                              
R1         10k          TopLayer RESC0603X03L_C              31.496        -157.480      270      "Resistor, ±1%, 0.05W"                                                                                                              
C4         10µF         TopLayer CAPC1608X06L                211.614       -24.606       180      "Capacitor, X5R, ±20%"                                                                                                              
C2         10µF         TopLayer CAPC1608X06L                -174.213      61.024        270      "Capacitor, X5R, ±20%"                                                                                                              
C5         1.0µF        TopLayer CAPC1608X06L                211.614       114.173       180      "Capacitor, Ceramic, 1.0µF 10V X5R 0603,±10%"                                                                                       
C6         2.2µF        TopLayer CAPC1608X06L                211.614       -114.173      180      "Capacitor, Ceramic, X7R, ±10%, 16V"                                                                                                
L1         2.2µH        TopLayer INDC2016X10N                -248.031      79.724        270      "Inductor, Irms=2.5A, Isat=2.9A, ±20%, DCR=73mO"                                                                                    
L2         2.2µH        TopLayer INDC2016X10N                -267.716      -40.354       0        "Inductor, Irms=2.5A, Isat=2.9A, ±20%, DCR=73mO"                                                                                    
C1         1.0µF        TopLayer CAPC1608X06L                211.614       24.606        180      "Capacitor, Ceramic, 1.0µF 10V X5R 0603,±10%"
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

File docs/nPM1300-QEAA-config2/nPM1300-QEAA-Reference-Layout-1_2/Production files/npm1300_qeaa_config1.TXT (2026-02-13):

M48
;Layer_Color=9474304
;FILE_FORMAT=2:4
INCH,TZ
;TYPE=PLATED
T01F00S00C0.0098
T02F00S00C0.0120
%
T01
X-3465Y-2362
Y-1516
Y-551
Y177
Y1024
Y1870
Y2785
X-2441
X-1929
Y2087
X-2441
X-1319Y925
X-748Y1299
X-295Y1575
X246Y1368
X128Y2785
X-128
X-768
X758
X1378
X2756
Y1142
Y246
Y-246
Y-1142
Y-2362
X1850
X945
Y-1945
X197Y-1929
X-344Y-1945
X-98Y-1260
X-1673Y-1516
X-1831Y-1043
X-2402Y-1516
Y-2362
X-1673Y-2362
X-1742Y98
X-1457Y98
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

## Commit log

2026-01-26 create kicad project
    [ibm-modern-m-ssk.kicad_pcb, ibm-modern-m-ssk.kicad_sch]
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2026-01-26 Add KiCad project files for IBM Modern M SSK
    Added new KiCad project-related files: project state (.kicad_prl), updated project settings (.kicad_pro), and a backup ZIP. Updated fp-info-cache with new footprint information for 'ibm buckling spri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
2026-01-26 Add matrix schematic and update project structure
    Added new matrix.kicad_sch schematic file and integrated it as a subsheet in ibm-modern-m-ssk.kicad_sch. Updated project and schematic settings in ibm-modern-m-ssk.kicad_pro and adjusted selection fi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
    [ibm-modern-m-ssk.kicad_sch, matrix.kicad_sch]
2026-01-26 matrix update
    [matrix.kicad_sch]
2026-01-26 Add new symbols to schematic and update selection filter
    Added symbols for MCP73831-2-OT, USB_C_Receptacle_USB2.0_14P, R_Small, and MDBT50Q-1MV2 to ibm-modern-m-ssk.kicad_sch. Updated selection filter in ibm-modern-m-ssk.kicad_prl to enable all item types.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
    [ibm-modern-m-ssk.kicad_sch, matrix.kicad_sch]
2026-01-26 Add new KiCad backup files and clean up temp files
    Added several new backup ZIP files for the IBM Modern M SSK project. Removed auto-saved and lock files to clean up the project directory.
2026-01-27 Add new connectors and components to schematic
    Added symbols for Conn_01x02_Socket, Conn_02x06_Odd_Even, C_Small, Crystal_Small, LED_Small_Filled, and USBLC6-2P6 to ibm-modern-m-ssk.kicad_sch. Updated schematic to include these components. Added 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
    [ibm-modern-m-ssk.kicad_sch]
2026-01-31 Schematic done
    [ibm-modern-m-ssk.kicad_sch]
2026-02-01 Schematic Done v2
    [ibm-modern-m-ssk.kicad_sch, matrix.kicad_sch]
2026-02-01 Add KiCad autosave reference and backup zips
    Add kicad/#auto_saved_files# pointing to _autosave-ibm-modern-m-ssk.kicad_sch and include multiple timestamped backup ZIP archives under kicad/ibm-modern-m-ssk-backups (2026-01-31 to 2026-02-01). The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
2026-02-01 Add SW-SMD_L3.9-W3.0-P4.45 footprint
    Add new KiCad pretty module kicad/libraries/easyeda2kicad.pretty/SW-SMD_L3.9-W3.0-P4.45.kicad_mod. The footprint defines an SMD toggle switch with two rectangular pads (at ±2.18 mm, size 1.23×1.86 mm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
2026-02-01 Footprints & BOM done
    [ibm-modern-m-ssk.kicad_sch, matrix.kicad_sch]
2026-02-01 Rotate KiCad backups; update autosave list
    Add _autosave-matrix.kicad_sch to kicad/#auto_saved_files# and rotate ibm-modern-m-ssk backup archives: remove three older zips (..._000924.zip, ..._001918.zip, ..._004606.zip) and add three new ones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
2026-02-01 Update KiCad schematic, project files and backups
    Rotate backups, and adjust KiCad project/schematic files. Deleted kicad/#auto_saved_files# and removed an old backup; added two new ibm-modern-m-ssk backup zips. Updated kicad/ibm-modern-m-ssk.kicad_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
    [matrix.kicad_sch]
2026-02-05 Add LiPo STEP/module and backups, update schematic
    Add LiPo_603450_1200mAh STEP (3D) and corresponding .kicad_mod to the easyeda2kicad libraries, add two ibm-modern-m-ssk backup ZIPs, and update kicad/matrix.kicad_sch. Remove stale PCB lock file (~ib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
    [matrix.kicad_sch]
2026-02-05 Import complete KiCad PCB, schematic & footprint
    Add full KiCad PCB file (ibm-modern-m-ssk.kicad_pcb) including board setup, layers, nets and populated footprints (generated by pcbnew 9.0). Update project files (.kicad_prl, .kicad_pro, .kicad_sch) 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
    [ibm-modern-m-ssk.kicad_pcb, ibm-modern-m-ssk.kicad_sch]
2026-02-05 Clean up fp-info-cache and update checksum
    Remove numerous obsolete or duplicate footprint entries from kicad/fp-info-cache (multiple capacitor THT variants, several connector blocks including Hirose FX10, DEC PCBEdge, M.2 variants, Samtec Ed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
2026-02-07 Adjust KiCad schematic text properties
    Update kicad/ibm-modern-m-ssk.kicad_sch to standardize text formatting: increase several font sizes and thicknesses and tweak one label position for consistency. Add .gitignore entry to ignore kicad/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
    [ibm-modern-m-ssk.kicad_sch]
2026-02-07 nrf52840_qiaa reference circuit
    [nrf52840_qiaa_config1.DRL, nrf52840_qiaa_config1.GBL, nrf52840_qiaa_config1.GBO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]
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2026-02-07 Add nrf52840_qiaa KiCad library entries
    Register new KiCad libraries for the nRF52840 QIAA design: add a footprint library entry (nrf52840_qiaa) to kicad/fp-lib-table and a symbol library entry (nrf52840_qiaa_config5) to kicad/sym-lib-table so the project can resolve the custom footprints and symbols.
2026-02-09 update mcu
    [ibm-modern-m-ssk.kicad_pcb, ibm-modern-m-ssk.kicad_sch, matrix.kicad_sch]
2026-02-09 update lolololololololo
    [ibm-modern-m-ssk.kicad_sch]
2026-02-13 update - change pmic to npm1300
    [ibm-modern-m-ssk.kicad_sch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]
2026-02-19 update - pcb layout
    [ibm-modern-m-ssk.kicad_pcb, ibm-modern-m-ssk.kicad_sch, nrf52840_qiaa_config5.kicad_pcb]
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2026-10-06 Add calibration measurement PDFs
    Add two calibration documents under docs/measurements: calibration_1905_2084.pdf and calibration_19_21.pdf. These PDFs contain measurement/calibration data for project reference and are included in t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
2026-10-17 chore: clean up .gitignore and remove generated KiCad files
    - rewrite .gitignore (KiCad backups/locks/caches/.kicad_prl/.history,
    Fabrication Toolkit output, .baseline/, LaTeX, OS files)
    - remove fp-info-cache, lock files, missing3Dmodels logs,
    easyeda2kicad.bak (older subset of easyeda2kicad.kicad_sym)
    - remove nPM1300 reference-project backups and kicad/production
    (test output, regenerated by Fabrication Toolkit)
    - stop tracking .kicad_prl (kept on disk, local UI state)
    Claude-Session: https://claude.ai/code/session_01Sr7xChMF7s3qucTt6F9wNn
2026-10-17 refactor: move non-KiCad files into reference/, docs/, mechanics/
    Pure renames (git mv), no content changes:
    - docs/FSSK v1.00 -> reference/fssk-v1.00 (third-party FSSK)
    - docs/nPM1300-QEAA-config2 -> reference/nordic/npm1300-qeaa-config2
    - docs/nrf52840_qiaa_config5 -> reference/nordic/nrf52840-qiaa-config5
    - docs/*_PS_*.pdf -> docs/datasheets/
    - docs/measurements -> mechanics/measurements
    - docs/usbc diagram.drawio -> docs/diagrams/usbc-diagram.drawio
    Nordic reference projects moved as whole directories, so their
    ${KIPRJMOD}-relative library tables still resolve.
    Claude-Session: https://claude.ai/co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
2026-10-17 docs: add CLAUDE.md migration notes and 3D model path checker
    - CLAUDE.md: closed decisions, repo rules, migration status and the
    remaining steps (0a/0b baseline + KiCad 10 upgrade, 3, 4, 5, 6),
    target tree, known issues, phase-2 items
    - tools/check_3d_paths.py: verifies (model ...) paths in .kicad_pcb
    and .kicad_mod resolve to existing files (for step 4)
    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
2026-10-20 fix(controller): restore footprints and LCSC fields lost on symbol update; PMIC P5, S2, P8, P9
    Footprint and LCSC Part restored from 6fba3e8 for every symbol whose value
    is unchanged (MB and DB); J8/J9 descriptions restored. Q1 (now AO3401A)
    left for manual footprint assignment.
    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
2026-10-20 feat(lib): nRF52840 unit titles, VDDH next to VDD
    Each unit gets a vertical title (SUPPLY, DEC, CLOCK / RF / USB,
    GPIO P0, GPIO P1 / SWD). VDDH shares VDD_NRF in normal voltage mode,
    so it joins the VDD group and the supply unit is five rows shorter.
    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
2026-10-21 feat(controller): nRF52840 pins for I2C, PMIC_INT, LED_EN, SWO, RESET
    SDA P0.13, SCL P0.14, PMIC_INT P1.01, LED_EN P1.02, SWO P1.00,
    P0.18/RESET to SW90. Changelog: P5, P6, F1, F2, M3 applied; M2 partial
    (J10 pin 3 still on GND).
2026-10-21 feat(controller): Tag-Connect pin 3 on RESET (M2)
    J10 pin 3 moved from GND to RESET with P0.18 and SW1 (renamed from
    SW90). Changelog: M2 applied.
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2026-10-25 feat(controller): expansion connector J3 as 2x3 1.27 mm SMD header (S3)
    VSYS, VDD_NRF, GND, EXT_INT (P0.19), SCL, SDA. Replaces the 2x6
    layout from S1; HARDWARE_DECISIONS updated.
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2026-10-25 feat(controller): VBUS protection F1/D1, TPD4E05U06 symbol, ERC power flags (I3)
    - F1 SMD1210-110-24V (C22436715), D1 SMF20A (C123788) as D_Zener_Small, cathode on DB_VBUS
    - U3 on new ibm_m:TPD4E05U06DQA symbol, connections unchanged
    - ERC sheet with PWR_FLAG for VBUS, VBAT, PVSS2, DB_VBUS, DB_GND
    - C19 footprint 0402
    - docs: I3 applied, J2 = JST PH, WS2812C VIH resolved
2026-10-26 feat(controller): split schematic into pages, JLC BOM, RF config 7 (A13, A14, M5, P9)
    - Schematic split into Power, MCU Core, MCU IO and Daughterboard pages;
    motherboard.kicad_sch and ERC.kicad_sch removed, cross-page signals as
    global labels. J3 pins 1-3 fixed (local labels did not join power nets).
    - R1/R2 0R in series with SCL/SDA to J3.
    - RF matching per nRF52840 reference config 7 (C3 1.0p, L1 4.7n, C4 1.2p,
    L5 2.2n), C22 removed.
    - BOM for JLC assembly: passives moved to basic parts, R10 LCSC fixed
    (470k 0603), C16 0603, C9 DNP; Q2 AO3401A (new ibm_m symbol);
    SW1 TS-1187A-B-A-B; D2 WS2812B-2020-V6; J6 U.FL-IPEX-1 (pads renumbered).
    - ERC 0 errors / 0 warnings; tools/kicad-che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
2026-10-26 feat(controller): update PCB from schematic, footprint cleanup, DRC in check script
    - PCB updated from the split schematic: new parts placed (C19, C35, D2, J3,
    L5, NT1, Q2, R1/R2, R11/R12, SW1, TP1), old ones removed (D4, D92,
    SW89-91, old Q1, C10), footprints replaced (J2 JST PH, J8/J9 1x10 1.0 mm,
    F1 1210, D1 SOD-123F).
    - Footprint fixes: J1 shield pads, pad rounding, silkscreen; standard
    footprints with local changes copied to ibm_bs.pretty (JST PH, headers,
    SOT-23, test pad).
    - tools/kicad-check.sh: PCB DRC with schematic parity.
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2026-11-01 fix(lib): footprint attributes and pads, PCB footprint refresh (29-30.10)
    attr smd for aQFN73 (U1), QFN32 (U2) and WS2812B-2020 (D2); pad updates in JST PH S2B, 1x10 SMD header and TestPoint_Pad. PCB saved after footprint changes; R3 and TP2-TP14 not yet on board (Update PCB pending).
2026-11-01 docs: sync CLAUDE.md and HARDWARE_DECISIONS with current schematic
    MB-DB pinout per I6, migration checklist replaced by short repo state, current stage; D2 WS2812B-2020-V6, C35, R11/R12, R10 0603, SW1 in docs; closed open items (pre-audit BOM, assigned GPIO).
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2026-11-03 feat(controller): JLC board setup, netclasses, +3V3 net names, board outline
    Board Setup per JLC capabilities: ENIG, annular 0.1, hole-to-hole 0.25, hole clearance 0.2, silk 0.15/1.0, mask web 0.1; netclasses USB (0.16/0.13), RF_50ohm (0.2, clearance 0.15), Power with per-net patterns. Old routing and zones removed. Nets VDD_NRF -> +3V3_NRF, BUCK2 output -> +3V3_BUCK. J2, J8, J9 excluded from BOM and position files. U1/U2 library footprints: pad mask/paste margins reset to board defaults. MB and DB outlines imported to Edge.Cuts.
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2026-11-08 wip(controller): MB placement (U1 180 deg, U2, J9 at S1), nRF52840 core routing, board setup
    - U1 rotated 180 deg (ANT to the left), RF chain C3-L1-C4-L5 to J6, crystals Y1/Y2 and
    REG1 parts moved next to U1; nPM1300 block (U2, L4, C27-C33, R10) shifted
    - J9 placed at S1 (175.0, 86.025); PinHeader_1x10_P1.00mm_Vertical origin centred
    - routed: XC1/XC2, XL1/XL2, DEC1/3/4/5, DECUSB, DCC, ANT and RF chain, +3V3_NRF caps;
    DB_VBUS/F1 and DB CC/D+/D- touch-ups
    - board setup: track 0.2, PTH 0.3, copper-edge 0.5, hole clearance 0.25, silk 0.1,
    USB netclass clearance 0.13
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2026-11-08 fix(lib): NetTie-2_SMD_Via0.45mm concentric (via under SMD pad)
2026-11-08 feat(tools): rename fanout_vias to via-o-tronic, lead/45/lead routing, pictogram dialog
    - new routing mode: straight lead from the pad (A), 45 deg jog, straight lead into
    the via (B); sideways shift of the via row (S); choice which lead takes the slack
    - track width, via diameter and drill editable separately (empty = netclass)
    - dialog (dialog.py): pictogram with all dimensions as editable fields, remaining
    options in a compact grid, Win95-style logo and new icons
    - autoroute no longer reports bend warnings from the fallback plan
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2026-11-08 feat(via-o-tronic): via row placed by D/S, obstacle avoidance, clearer sketch, faster router
    - A/45/B mode keeps the via row where D and S put it; the 45 deg jog adapts, so
    changing S no longer pushes the row away; D from works in every mode
    - Avoid: planned tracks that would hit pads, tracks or vias of other nets (also the
    other planned vias) are rerouted on the grid router, colliding vias moved
    - sketch with lettered dimensions, values in a column beside it, hovered/focused
    dimension highlighted; track length readout L (min-max)
    - obstacles collected once per dialog, analytic row-span rasterization (same result,
    ~18x faster), avoidance tries a single router window
    - Move vias arrow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
2026-11-08 feat(via-o-tronic): zigzag via layout, grouped problem log with hints
    - Vias: Row / Zigzag; in zigzag every second via sits Z farther, auto P allows a
    track between two near vias, empty Z = smallest that keeps via clearance
    - problems grouped per kind and items with a hint what to change; warning button
    opens a live log window (Copy); on OK a line is appended to via_o_tronic.log
    next to the board
    - via diameter and drill on one row
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2026-11-09 feat(spacing-o-matic): KiCad plugin to measure and set the spacing of parallel tracks
    Selected bus at any angle: pitch / gap measured now, set to one value or per pair,
    keep first / centre / last, shift S, width W. Changes go straight onto the board
    (OK keeps, Cancel restores exactly, one undo step). Track ends slide along their
    neighbours (45 deg stays 45 deg) or get 45 deg jogs at pads / vias. Clearance check
    against other copper and the netclass. Win95-style dialog like via-o-tronic.
    Tests: geometry (random buses), real pcbnew (ratsnest, KiCad DRC agreement), GUI.
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2026-11-09 feat(bus-o-matic): continue several parallel tracks together at one pitch
    Straight, 45/90 bend, jog or U-turn from the open ends of the selected tracks;
    ends squared first, 45 deg fan when the pitch changes (neighbours never closer
    than the smaller pitch), corners sharp or cut with the spacing kept. Live on
    the board, OK keeps, Cancel restores, one undo step. Clearance check agrees
    with KiCad DRC in the tests.
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2026-11-11 feat(net-o-matic): fast net change of selected tracks and/or vias
    Type a few letters, the virtual net list narrows (nets the copper touches
    first, then recent), Enter = OK. Live on the board, Tracks/Vias toggles
    (vias alone work), + connected (same old net, stops at pads), Swap of two
    nets, no net, new net, pads/zones in More, short warnings. One undo step.
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2026-11-11 wip(controller): PCB routing 10-11.11, JLC board setup, DB panel, pin remap
    - Board Setup: JLC minima (track 0.1, drill 0.15, edge 0.2, hole clearance 0.2,
    annular 0.05), missing_courtyard = warning
    - mb_pcb: right DB bridge removed, mouse bites 8 x 0.5 mm at 0.75 mm pitch,
    outline closed; J8 pads 0.2 mm from the DB edge
    - schematic: SWO back on P1.00 (AD22), LED_EN P0.15 (AD10), EXT_INT P1.02 (W24),
    RGB_DIN P0.19 (AC15), PMIC_INT P0.17 (AD12), TP11 P0.22, TP12 P0.24,
    J10.1 and J3.2 on +3V3_BUCK, J4/J7 symbols without MP
    - PCB: USB D+/D-, CC1/CC2, VBUS to J9, RF line L5 to J6 with via fence,
    SWD/I2C bus, C19, SW1, R1, R2 placed
    - state: ERC 0, parity 0, DRC 18 errors, 145 unconnect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

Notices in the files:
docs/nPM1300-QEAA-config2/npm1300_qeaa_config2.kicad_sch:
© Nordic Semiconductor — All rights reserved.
